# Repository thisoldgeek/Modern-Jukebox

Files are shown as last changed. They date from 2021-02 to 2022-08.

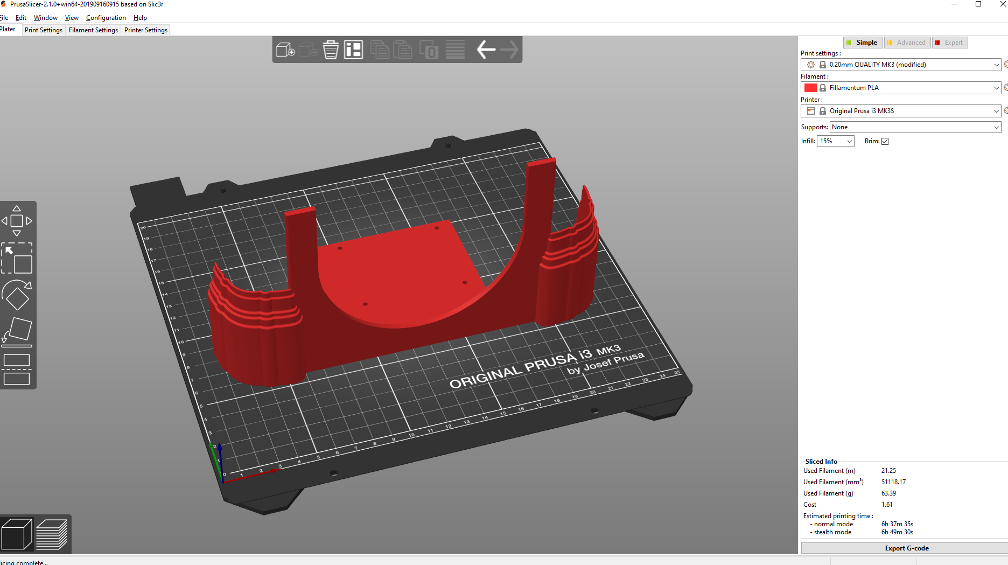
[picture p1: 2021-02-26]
3D-Prints/Bottom.png

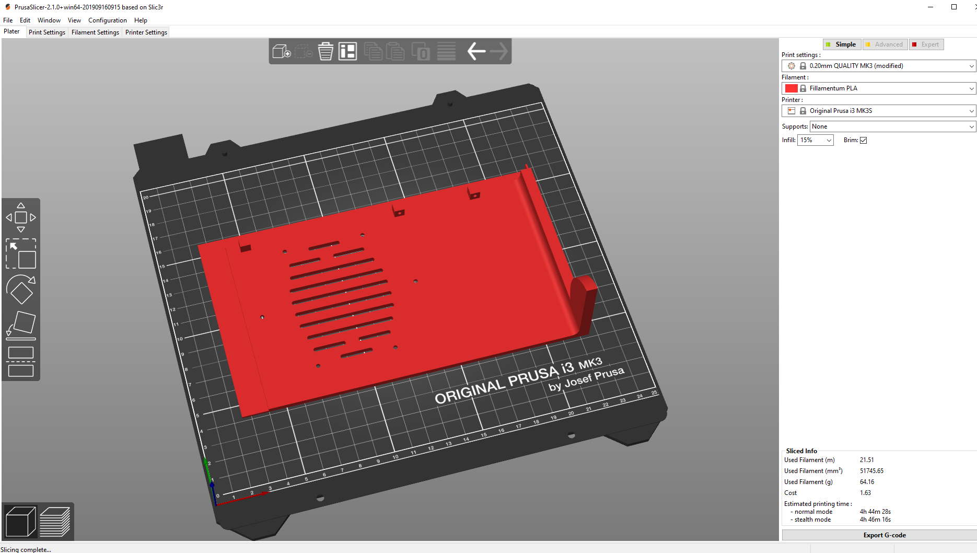
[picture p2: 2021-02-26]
3D-Prints/CaseLeft.png

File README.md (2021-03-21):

# **Modern Jukebox**
Modern-Jukebox-Small
 	 	
# *Attributions:*
Classic Jukebox by Marco Gregorio 
https://grabcad.com/library/classic-jukebox-1

Arduino sketch, Music Visualizer by Michael Bartlett
https://learn.sparkfun.com/tutorials/interactive-led-music-visualizer/all

## *Description:*
A 3D-printed Jukebox powered by Volumio, with NeoPixel LEDs that react to sound/music.
Plays your own music, web radio, Pandora, Spotify and Apple AirPlay.

See the posting at:
https://www.hackster.io/thisoldgeek/modern-jukebox-bd1f4c

## *Required Hardware:*
* raspberry pi 3/4
* UCTronics Touch Screen 5in HDMI display, https://www.amazon.com/gp/product/B07VV7RL7Y/ref=ppx_yo_dt_b_search_asin_title?ie=UTF8&psc=1&fpw=alm
* 2x Dayton Audio RS100-8 Speakers (Parts Express)
* Adafruit perma-proto HAT, https://www.adafruit.com/product/2310
* Adafruit NeoPixel string 60 per Meter, https://www.adafruit.com/product/1461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
* IQAudio Pi Digi-Amp Plus, https://www.raspberrypi.org/products/iqaudio-digiamp-plus/
* HDMI 90 degree to 270 degree adapter, https://www.amazon.com/gp/product/B00Y7UT6EK/ref=ppx_yo_dt_b_search_asin_title?ie=UTF8&psc=1&fpw=alm
* HDMI flat, short cable: https://www.amazon.com/gp/product/B07RL574BB/ref=ppx_yo_dt_b_search_asin_title?ie=UTF8&psc=1&fpw=alm
* Miscellaneous screws, nuts, standoffs, 14AWG wire, jumper wires

## *Fabrication:*
* 3D print files in STL_files folder
* 3D printed case required; back case cover 3d parts optional
* See docs folder for 3D print settings
* Hot glue gun
* CA glue
* Soldeing Iron

## *Configuration:*
* Download and install Volumio; download and install Arduino sketch (*.ino) from this repo

## *REQUIRED:*
Intentionally blank

## *More Information:*
See the build log at https://www.hackster.io/thisoldgeek/modern-jukebox-bd1f4c
## *Update 02-25-2021:*
Initial install.

#

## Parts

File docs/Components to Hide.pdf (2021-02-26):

- Juke-enfeite lateral:2
- Juke-enfeite lateral:3
- Juke-button-panel
- Juke-frente-wurlitzer
- Juke-moeda-1:1
- Juke-base neon2:1
- Juke-tocadisco:1
- Juke-prato:1
- Juke-coin-out:1
- Juke-torre-braço:1
- Juke-moeda-outro:1
- juke espelhos lat:1
- juke espelhos lat:2
- juke espelhos lat:3
- juke espelhos lat:5
- juke espelhos lat:6
- juke lamp:1
- Peça3
- juke tecido falante:1

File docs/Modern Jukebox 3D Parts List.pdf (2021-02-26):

In Component | Name | Description | Looks Like This
Juke-madeira porta-1 | Arch | Together with Bottom, forms main body of jukebox.Frames the Grille

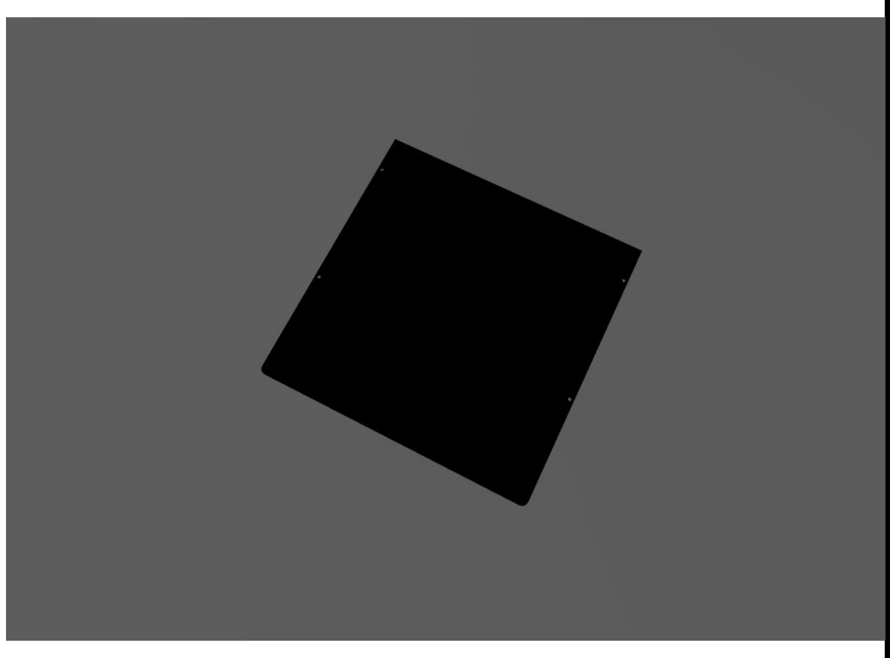
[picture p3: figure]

Juke-madeira:1 | Back Cover Bottom | Attached to Left/Right Panels to close the case

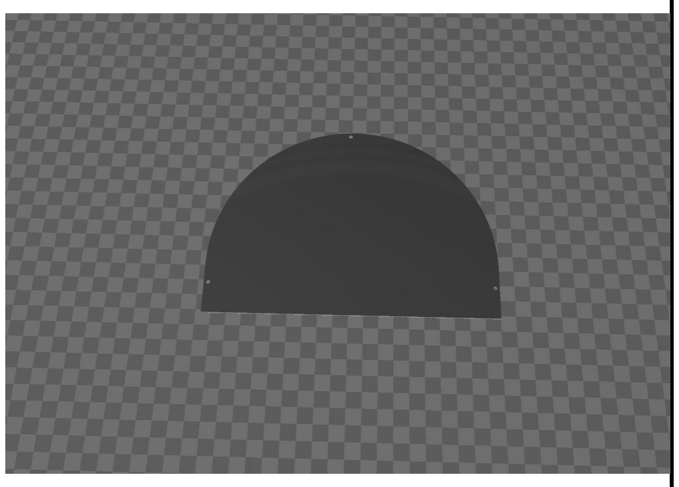
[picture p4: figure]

Juke-madeira:1 | Back Cover Top | Attached to Case Arch to close the case

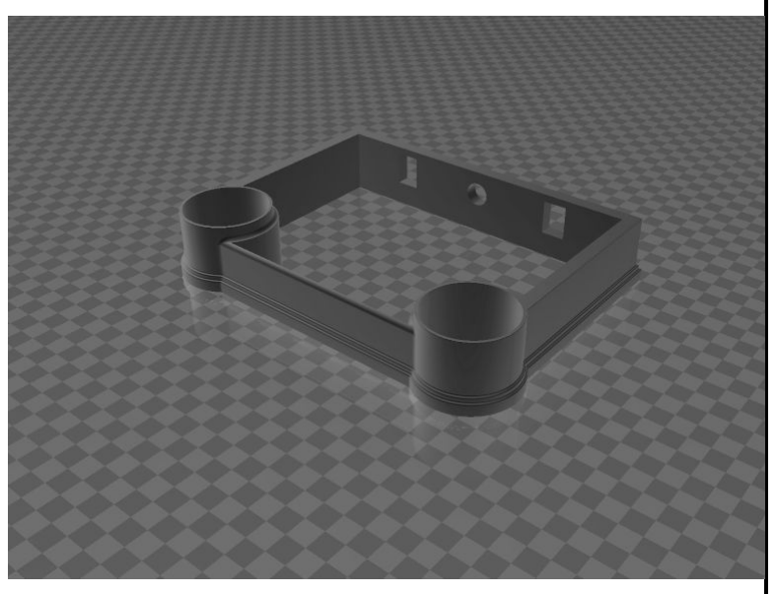
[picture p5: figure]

Jukebox - base inferior-1 | Base with switches | Attaches beneath main body of jukebox

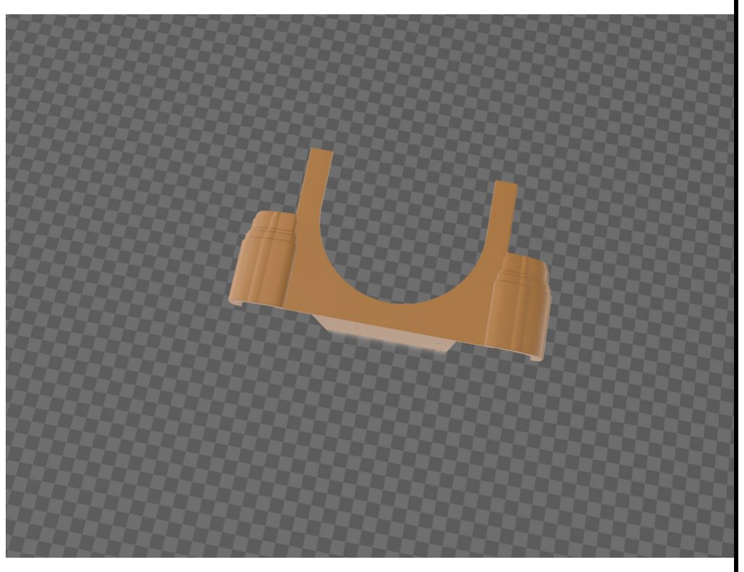
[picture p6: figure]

Juke-madeira porta-1 | Bottom | Main body of jukebox

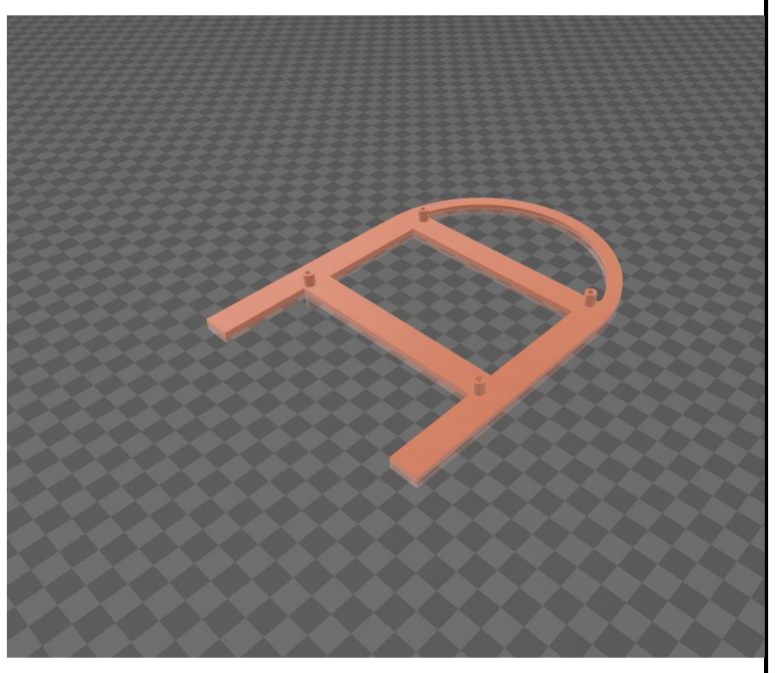
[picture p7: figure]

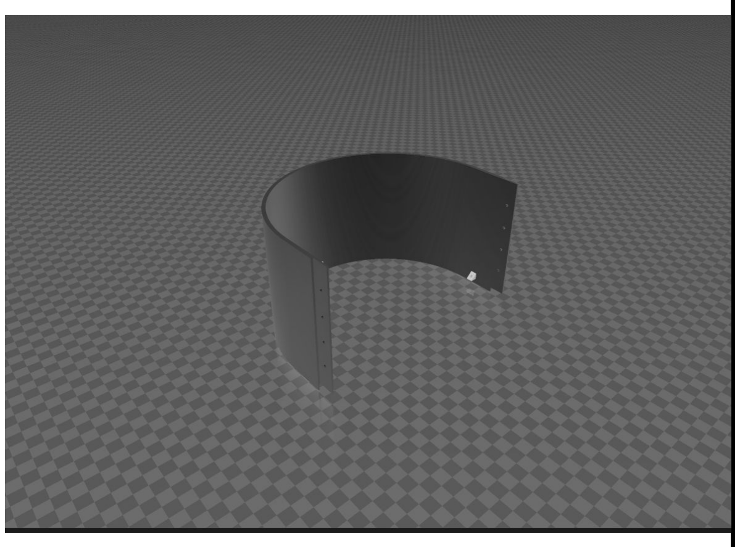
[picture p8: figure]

Juke-madeira:1 | Case Arch | Top arch behind neon tubes. Attached to left and right panels.

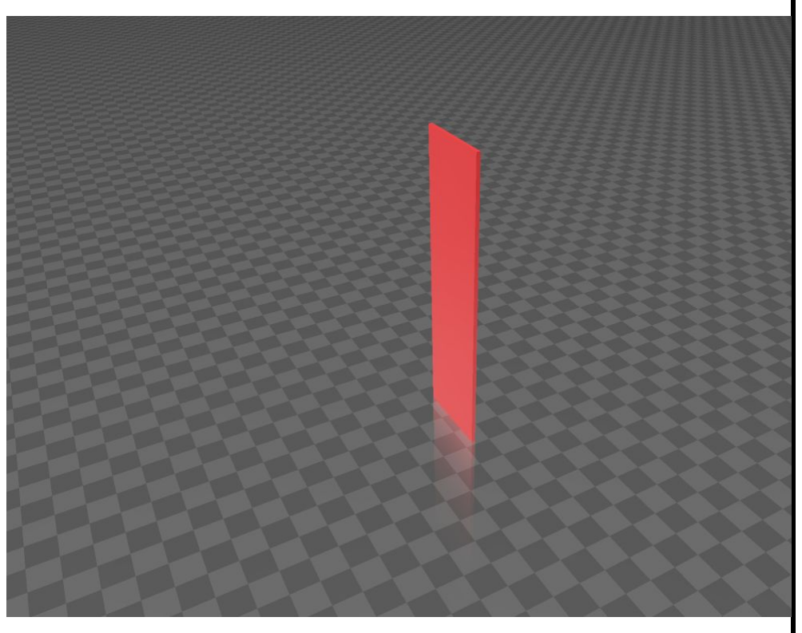
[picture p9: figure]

Juke-madeira:1 | Case Joint Cover | Hides the joint between the arch and the side panels. Two required.

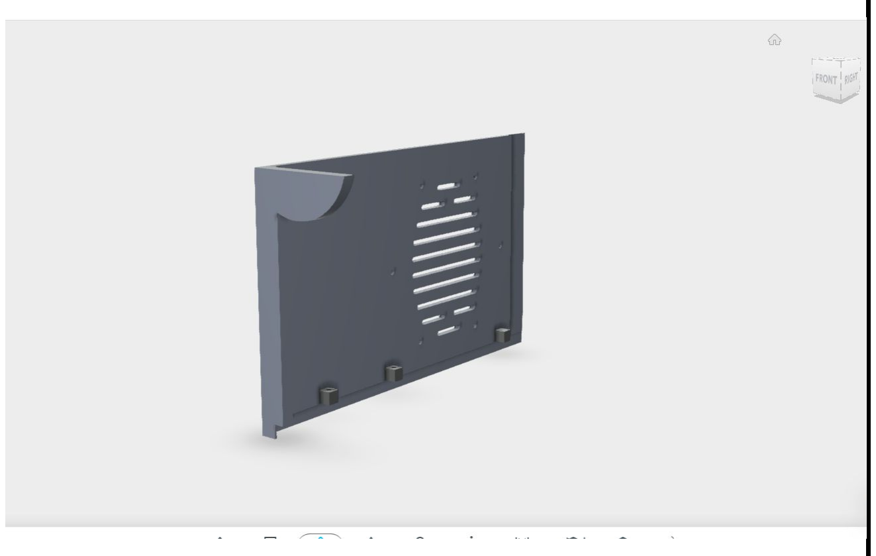
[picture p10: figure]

Juke-madeira:1 | Case Left | As you face the jukebox,case left panel behind the neon tubes.


Juke-madeira:1 | Case Right | As you face the jukebox, case right panel behind the neon tubes.


Juke-grande frontal2:1 | Grille | “Speaker” grille. Actually just a decorative piece. Speakers will be mounted on case sides.


Juke-grande frontal2:1 | Grille LED Holder | Holds an LED behind the grille light and acts as a light blocker on the back of the light


Juke-grande frontal2:1 | Grille Light | Illuminated insert for grille


Juke-neon interno:1 | Grille Tube | “Neon” frame around grille. Short string of LEDs will attach here.
Juke-neon-1 | Neon 1 Arch | Top arch to connect two side “neon” tubes. Thread long LED strip through this assembled component.


Juke-neon-1 | Neon 2 Tubes | Connects to Neon Arch. Thread long LED strip through these assembled components. Two tubes required.


JJuke-enfeite lateral-superior3 | Neon Tube Fan Decoration | Attached on top of Neon Tube Red Cover. Two required.


Juke-enfeite lateral:1 | Neon Tube Ornament | Attached on bottom of Neon Tube Red Cover. Two required.


Juke-neon:1 | Neon Tube Red Cover | Covers joints where neon tubes meet neon arch. Two required.


Juke-madeira:1 | Speaker Mount Ring | Adapter so Dayton Audio rs100-8 speakers will mount flush to panels. Two required.


Juke-topo-enfeite:1 | Top Ornament | Attached at top, center of Neon Arch. Two required (two bodies in STL file)..


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
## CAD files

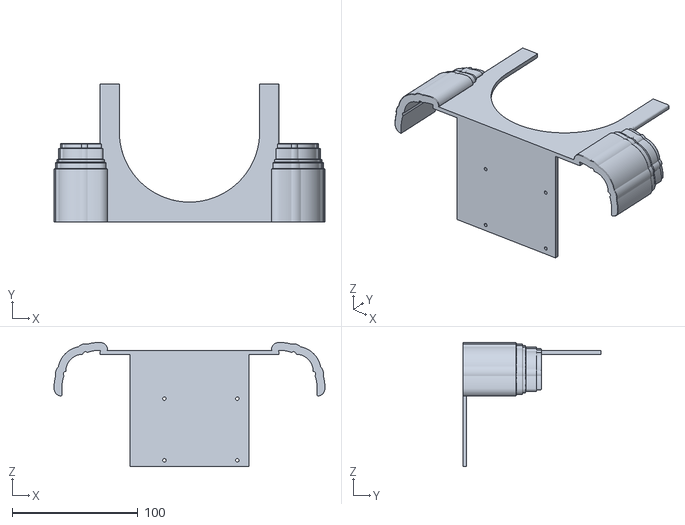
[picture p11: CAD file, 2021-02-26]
STL-files/Bottom.stl
215.5 x 110.0 x 98.8

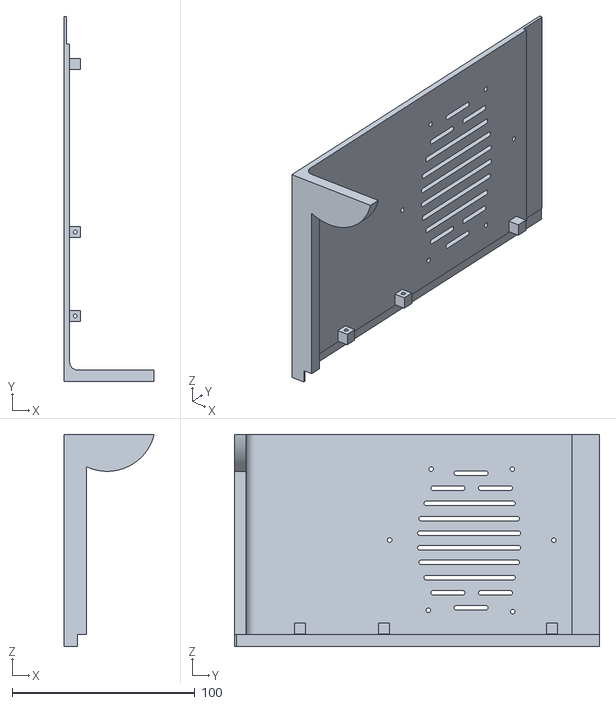
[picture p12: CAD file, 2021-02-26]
STL-files/CaseLeft.stl
49.6 x 200.0 x 116.2

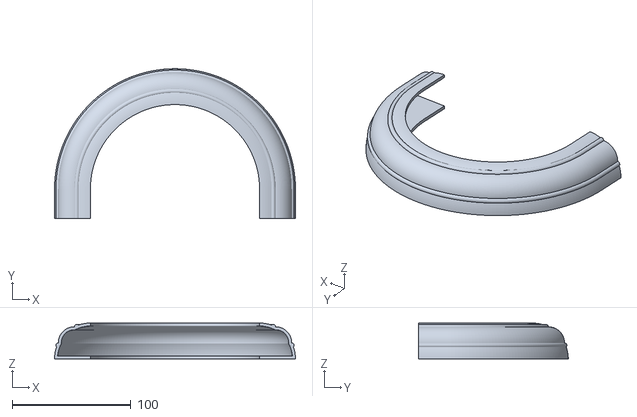
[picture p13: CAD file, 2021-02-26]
STL-files/Neon1Arch.stl
203.0 x 126.0 x 30.2

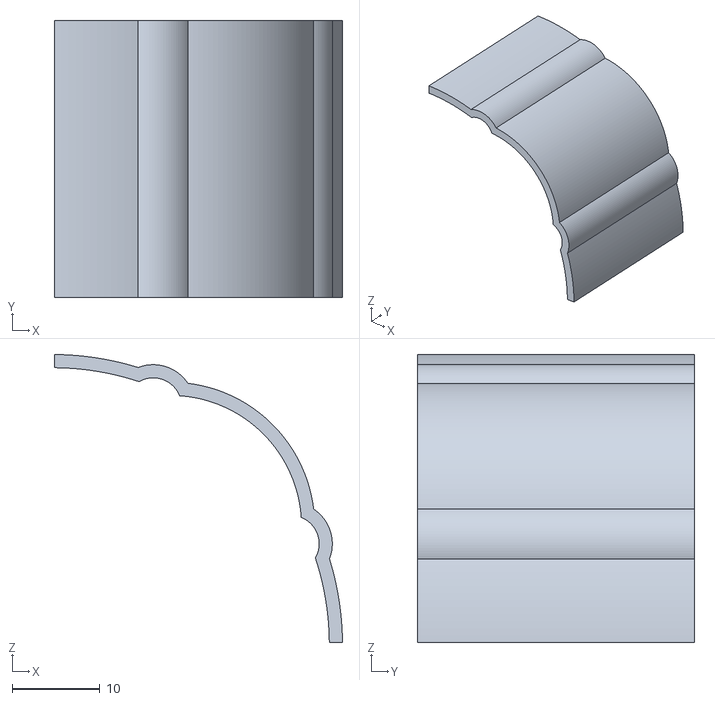
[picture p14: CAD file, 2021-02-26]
STL-files/NeonTubeRedCover.stl
32.7 x 31.5 x 32.7

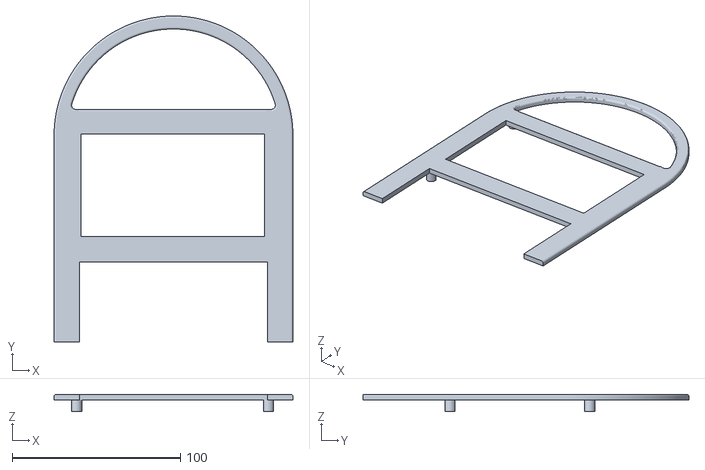
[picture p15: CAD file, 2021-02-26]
STL-files/Arch.stl
142.0 x 193.7 x 10.2

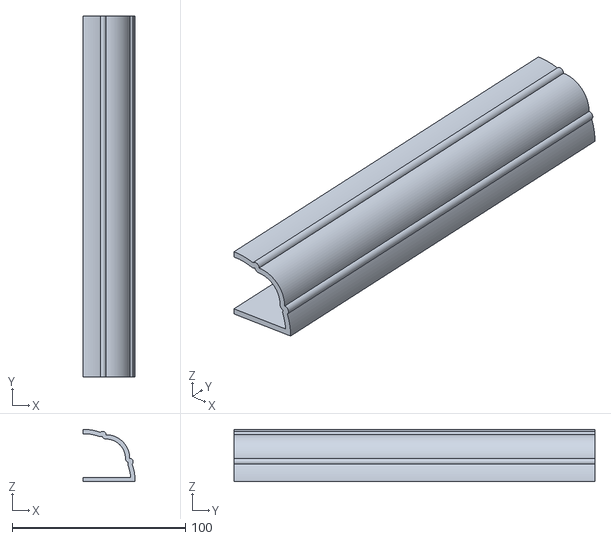
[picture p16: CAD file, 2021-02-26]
STL-files/Neon2Tubes.stl
30.2 x 208.2 x 30.2

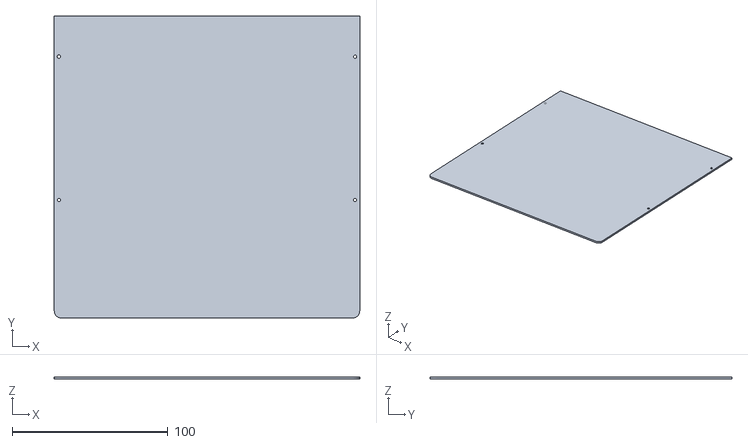
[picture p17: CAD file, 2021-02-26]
STL-files/BackCoverBottom.stl
196.0 x 193.7 x 1.50

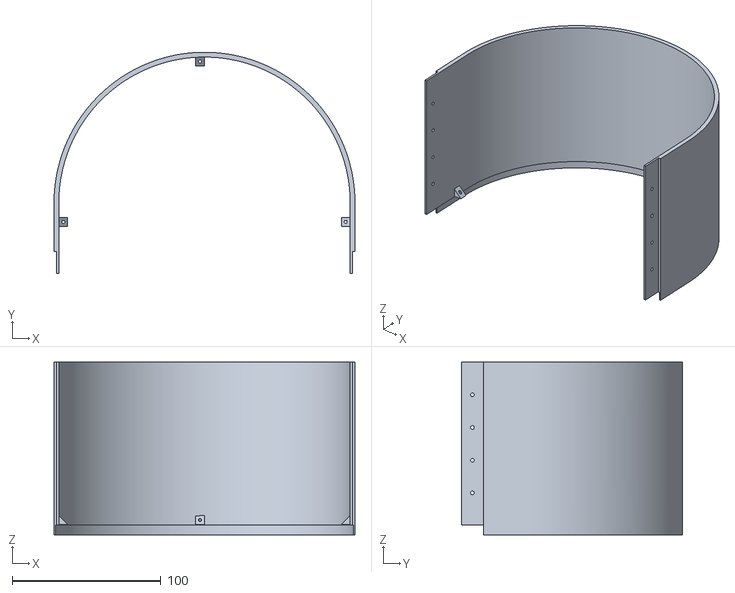
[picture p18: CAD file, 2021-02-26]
STL-files/CaseArch.stl
202.5 x 149.0 x 116.2

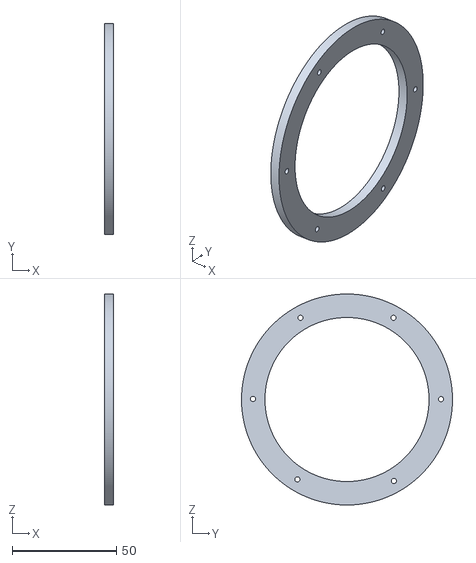
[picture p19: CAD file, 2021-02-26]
STL-files/SpeakerMountRing.stl
4.50 x 101.0 x 101.0

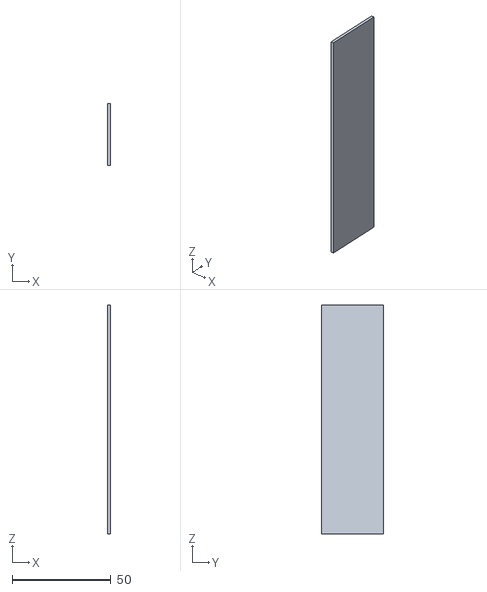
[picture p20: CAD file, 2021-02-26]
STL-files/CaseJointCover.stl
1.50 x 31.5 x 116.2

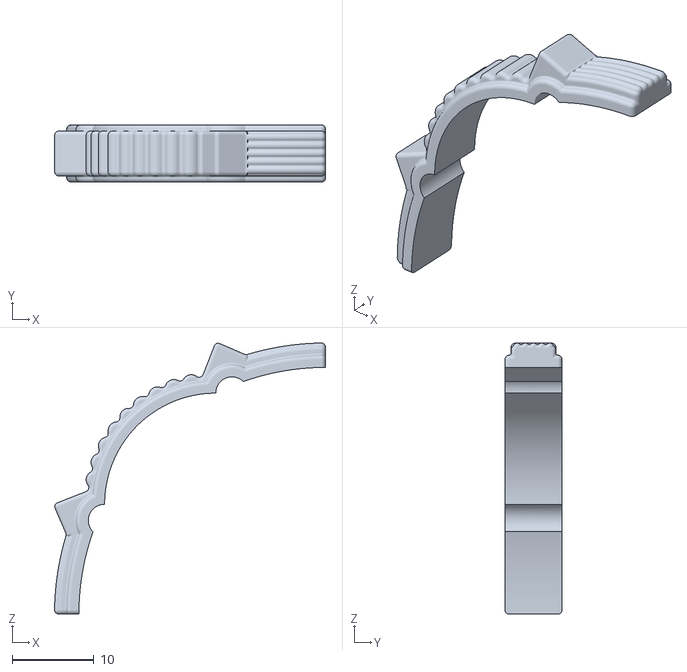
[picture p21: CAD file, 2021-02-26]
STL-files/NeonTubeOrnament.stl
33.2 x 7.00 x 33.2

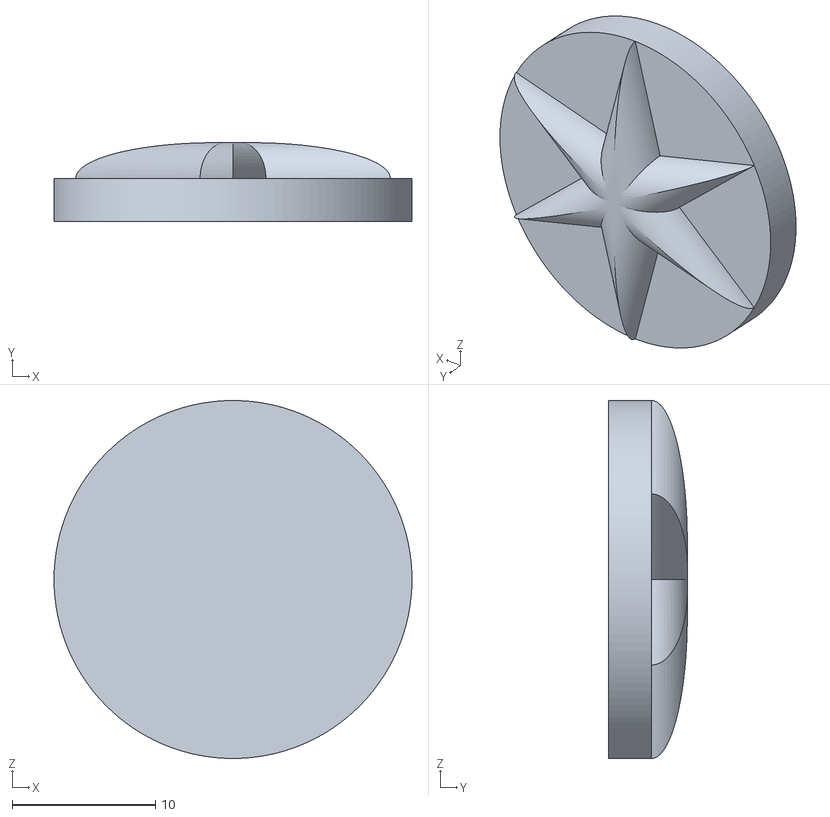
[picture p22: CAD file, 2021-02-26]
STL-files/GrilleLight.stl
25.0 x 5.50 x 25.0

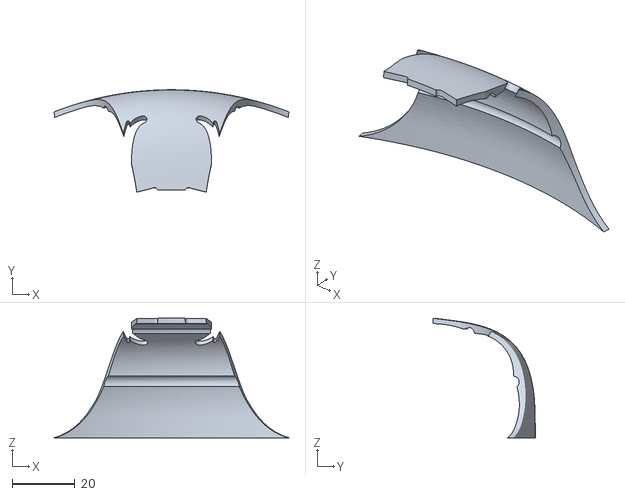
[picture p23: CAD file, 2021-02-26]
STL-files/TopRedOrnament.stl
75.2 x 32.8 x 38.2

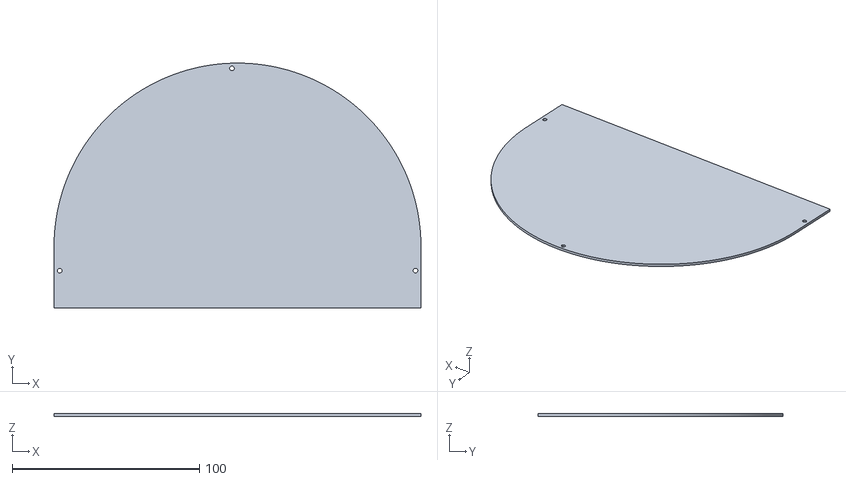
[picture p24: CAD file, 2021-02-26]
STL-files/BackCoverTop.stl
196.0 x 130.7 x 1.50

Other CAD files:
STL-files/CaseRight.stl
STL-files/GrilleTube.stl
STL-files/BaseWithSwitches.stl
STL-files/GrilleLEDHolder.stl

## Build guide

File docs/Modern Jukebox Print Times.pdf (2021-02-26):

Print Object | Print Time Supports Required?
Arch | 2:08:00
Back Cover Bottom | 4:04:00
Back Cover Top | 2:15:00
Base with Switches | 8:42:00
Bottom | 6:37:00
Case Arch | 12:08:00
Case Joint Cover | 0:28:00
Case Left | 4:44:00
Case Right | 4:45:00
Grille | 2:48:00
Grille LED Holder | 0:35:00
Grille Light | 0:12:00
Grille Tube | 4:25:00
Neon Arch | 8:48:00
Neon Tubes | 5:35:00
Neon Tube Fan Decoration | 0:26:00
Neon Tube Ornament | 0:19:00
Neon Tube Red Cover | 0:58:00
Speaker Mount Ring | 0:57:00
Top Ornament | 2:29:00
Top Red Ornament | 1:54:00
Total Print Time | 75:17:00

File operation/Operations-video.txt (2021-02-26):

Operations - https://youtu.be/HVOtVooQ_8A

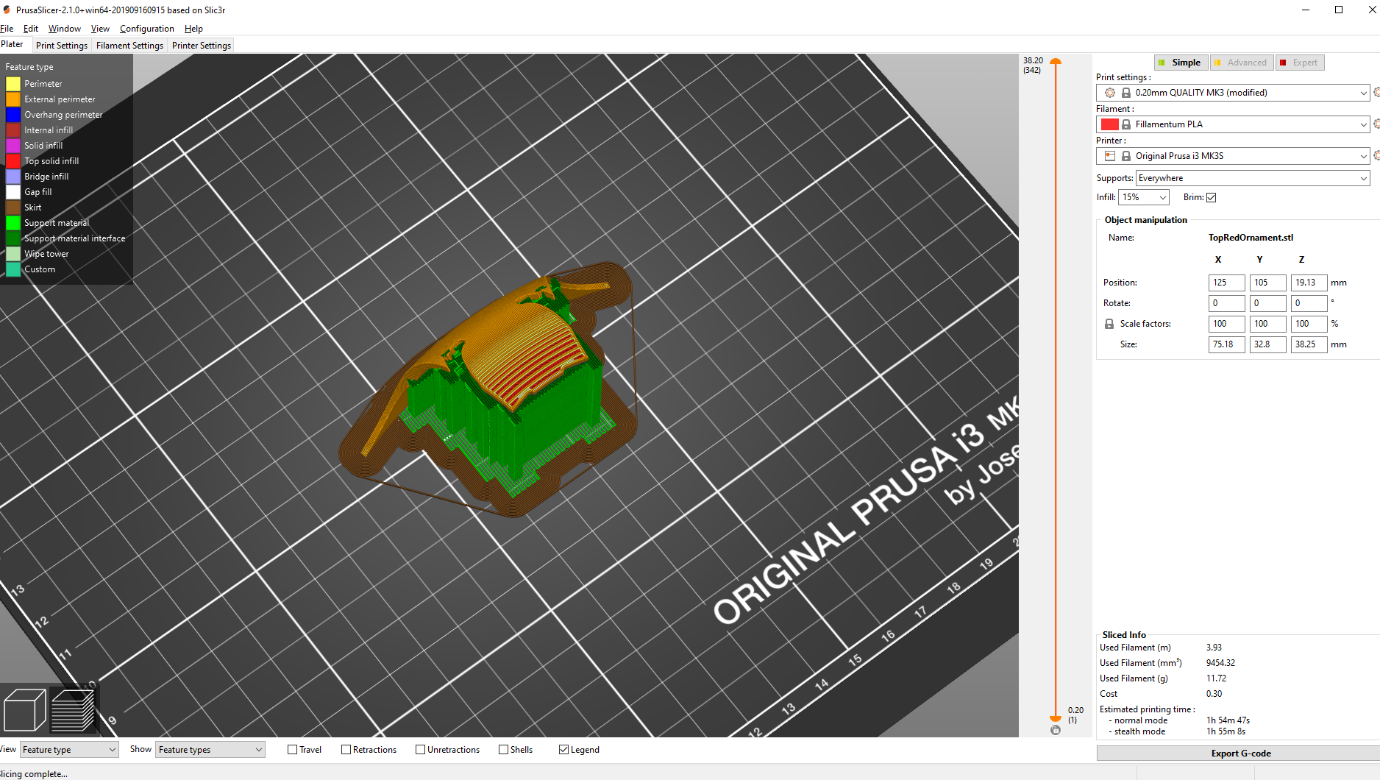
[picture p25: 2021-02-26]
3D-Prints/TopRedOrnament.png

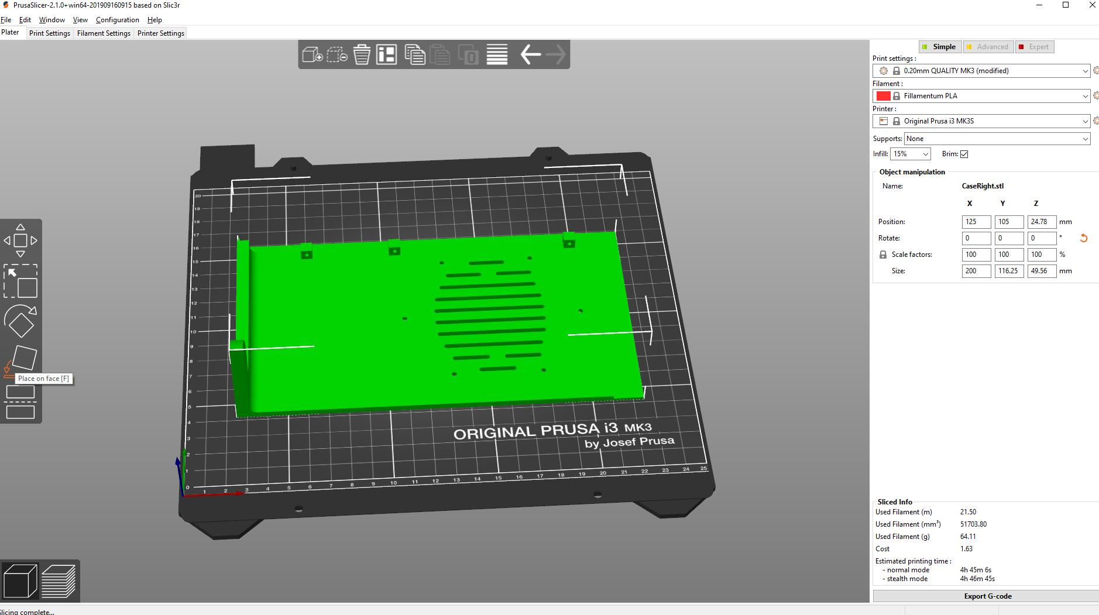
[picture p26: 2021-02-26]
3D-Prints/CaseRight.png

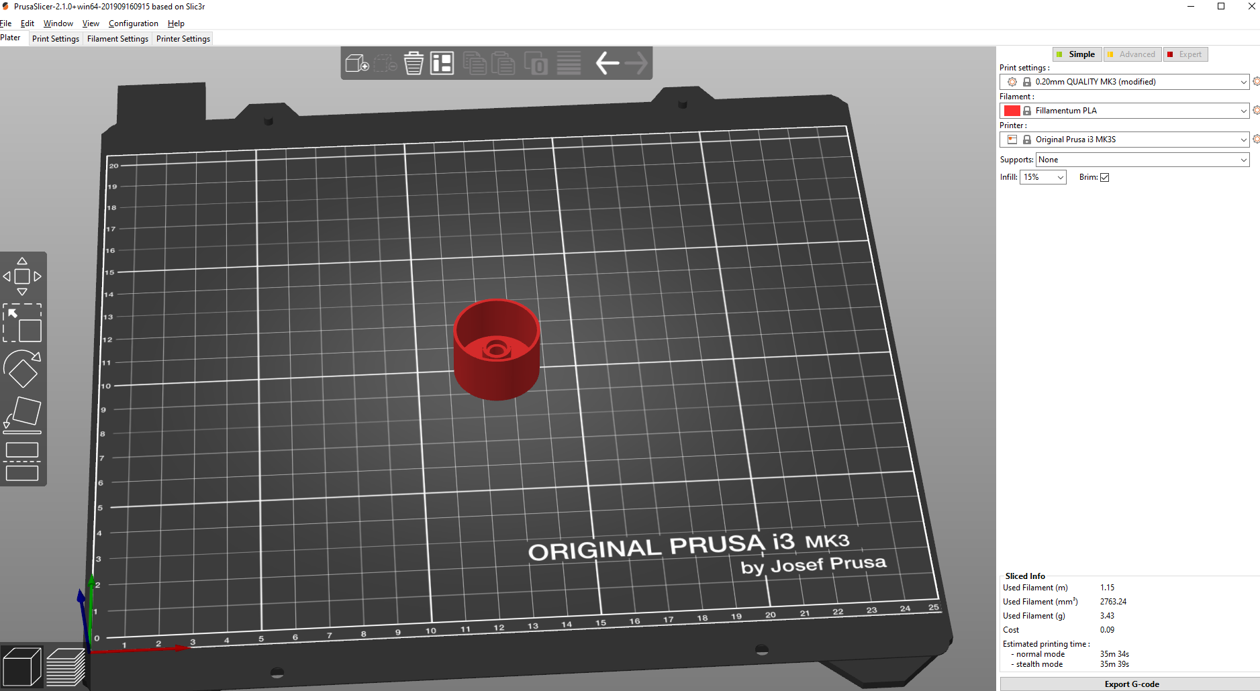
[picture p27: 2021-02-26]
3D-Prints/GrilleLEDHolder.png

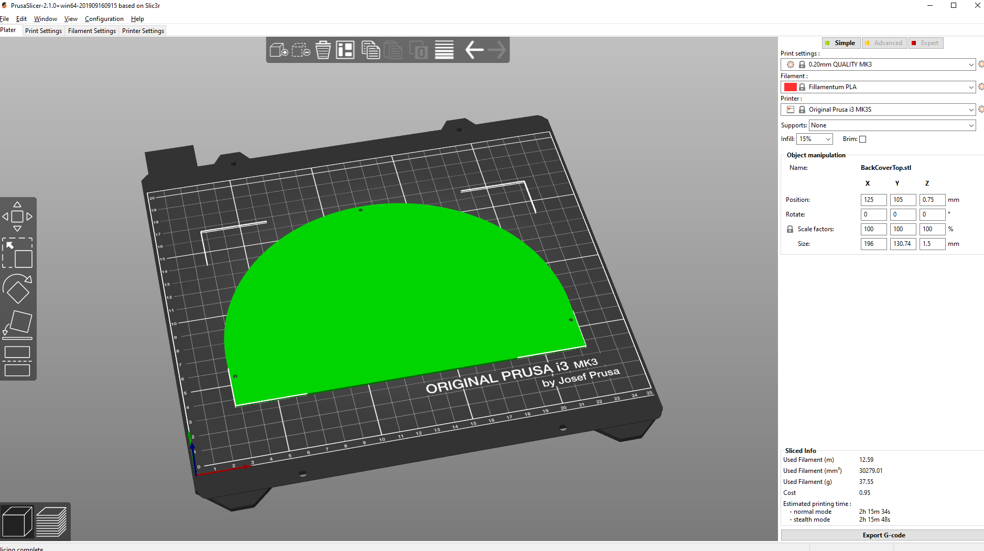
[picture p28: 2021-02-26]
3D-Prints/BackCoverTop.png

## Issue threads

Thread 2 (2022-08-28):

In animated lights mode, the lights don't track evenly up each side

Mark-Kiwi, 2022-08-28:
When switched to animated lights mode, I noticed the lights are not level as they sequence up each side.

To fix this, change the code as follows:
line 343
strand.setPixelColor(strand.numPixels()-(i+q), Wheel( (i+j) % 255));    //turn every third pixel on
change to
strand.setPixelColor(strand.numPixels()-1)-(i+q), Wheel( (i+j) % 255));    //turn every third pixel on

and line 351
strand.setPixelColor(strand.numPixels()-(i+q), 0);        //turn every third pixel off
change to
strand.setPixelColor((strand.numPixels()-1)-(i+q), 0);        //turn every third pixel off

thisoldgeek, 2022-08-29:
Applied

Closed 2022-08-29.

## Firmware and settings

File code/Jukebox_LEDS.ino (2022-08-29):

/* SparkFun Addressable RGB LED Sound and Music Visualizer Tutorial Arduino Code
 * by: Michael Bartlett
 * SparkFun Electronics
 * date: 2/7/16
 * license: Creative Commons Attribution-ShareAlike 4.0 (CC BY-SA 4.0)
 * Do whatever you'd like with this code, use it for any purpose.
 * Please attribute and keep this license.
*/
// Last Updated 20201211 15:30
//Libraries
#include <Adafruit_NeoPixel.h>  //Library to simplify interacting with the LED strand
#ifdef __AVR__
#include <avr/power.h>   //Includes the library for power reduction registers if your chip supports them. 
#endif                   //More info: http://www.nongnu.org/avr-libc/user-manual/group__avr__power.htlm

//Constants (change these as necessary)
#define LED_PIN   7  //Pin for the pixel tube strand. Can be analog or digital.
#define grille_LED_PIN   13  //Pin for the pixel grille strand. Can be analog or digital.
#define LED_TOTAL 36 //Change this to the number of LEDs in your strand
#define grille_LED_TOTAL 22 //Change this to the number of LEDs in your grille strand.
#define LED_HALF  LED_TOTAL/2
#define grille_LED_HALF  grille_LED_TOTAL/2
#define VISUALS   6   //Change this accordingly if you add/remove a visual in the switch-case in Visualize()

#define AUDIO_PIN A5  //Pin for the envelope of the sound detector
//#define KNOB_PIN  A1  //Pin for the trimpot 10K
#define BUTTON_1  6   //Button 1 cycles color palettes
#define BUTTON_2  5   //Button 2 cycles visualization modes
#define BUTTON_3  4   //Button 3 sw_poss shuffle mode (automated changing of color and visual)

//////////<Globals>
//  These values either need to be remembered from the last pass of loop() or
//  need to be accessed by several functions in one pass, so they need to be global.

// strand = outer "neon" tubes, used for music visualization
// strand2 = inner "grille_LED" tubes, constanly changing patterns. Not in sync with music
Adafruit_NeoPixel strand = Adafruit_NeoPixel(LED_TOTAL, LED_PIN, NEO_GRB + NEO_KHZ800);  //LED strand objects
Adafruit_NeoPixel grille_LED_strand = Adafruit_NeoPixel(grille_LED_TOTAL, grille_LED_PIN, NEO_GRB + NEO_KHZ800);  //LED grille strand objects


uint16_t gradient = 0; //Used to iterate and loop through each color palette gradually

//IMPORTANT:
//  This array holds the "threshold" of each color function (i.e. the largest number they take before repeating).
//  The values are in the same order as in ColorPalette()'s switch case (Rainbow() is first, etc). This is simply to
//  keep "gradient" from overflowing, the color functions themselves can take any positive value. For example, the
//  largest value Rainbow() takes before looping is 1529, so "gradient" should reset after 1529, as listed.
//     Make sure you add/remove values accordingly if you add/remove a color function in the switch-case in ColorPalette().
uint16_t thresholds[] = {1529, 1019, 764, 764, 764, 1274};

uint8_t palette = 0;  //Holds the current color palette.
uint8_t visual = 0;   //Holds the current visual being displayed.
uint8_t volume = 0;   //Holds the volume level read from the sound detector.
uint8_t last = 0;     //Holds the value of volume from the previous loop() pass.

float maxVol = 15;    //Holds the largest volume recorded thus far to proportionally adjust the visual's responsiveness.
//float knob = 1023.0;  //Holds the percentage of how twisted the trimpot is. Used for adjusting the max brightness.
float avgBump = 0;    //Holds the "average" volume-change to trigger a "bump."
float avgVol = 0;     //Holds the "average" volume-level to proportionally adjust the visual experience.
float shuffleTime = 0;  //Holds how many seconds of runtime ago the last shuffle was (if shuffle mode is on).

////////////////////////////////////////////////////////////////////////////////////////////////////////////////
//NOTE: The reason "average" is quoted is because it is not a true mathematical average. This is because I have
//      found what I call a "sequenced average" is more successful in execution than a real average. The difference
//      is that the sequenced average doesn't use the pool of all values recorded thus far, but rather averages the
//      last average and the current value received (in sequence). Concretely:
//
//          True average: (1 + 2 + 3) / 3 = 2
//          Sequenced: (1 + 2) / 2 = 1.5 --> (1.5 + 3) / 2 = 2.25  (if 1, 2, 3 was the order the values were received)
//
//      All "averages" in the program operate this way. The difference is subtle, but the reason is that sequenced
//      averages are more adaptive to changes in the overall volume. In other words, if you went from loud to quiet,
//      the sequenced average is more likely to show an accurate and proportional adjustment more fluently.
////////////////////////////////////////////////////////////////////////////////////////////////////////////////

//bool shuffle = false;  //sw_poss shuffle mode.
bool shuffle = true;  //sw_poss shuffle mode.
bool bump = false;     //Used to pass if there was a "bump" in volume

//For Traffic() visual
int8_t pos[LED_TOTAL] = { -2};    //Stores a population of color "dots" to iterate across the LED strand.
uint8_t rgb[LED_TOTAL][3] = {0};  //Stores each dot's specific RGB values.

//For Snake() visual
bool left = false;  //Determines the direction of iteration. Recycled in PaletteDance()
int8_t dotPos = 0;  //Holds which LED in the strand the dot is positioned at. Recycled in most other visuals.
float timeBump = 0; //Holds the time (in runtime seconds) the last "bump" occurred.
float avgTime = 0;  //Holds the "average" amount of time between each "bump" (used for pacing the dot's movement).

//////////</Globals>


//////////<Standard Functions>

// Selection Switch Pin Number
int sw_pos1 = 2;   //uses lights to music Visualizer routines
int sw_pos2 = 4;   //uses animated lights that don't react to music
int switch_choice; //whether switch is in 1, 2, or Off (== 0, center position)


void setup() {    //Like it's named, this gets ran before any other function.
  // Note: Following code works directly on Arduino Uno, 
  //       but on Micro, different behavior




  //Serial.begin(9600); //Sets data rate for serial data transmission.
  //Serial.println("Program Starting...");

  //Defines the buttons pins to be input.
  pinMode(BUTTON_1, INPUT); pinMode(BUTTON_2, INPUT); pinMode(BUTTON_3, INPUT);

  //Write a "HIGH" value to the button pins.
  digitalWrite(BUTTON_1, HIGH); digitalWrite(BUTTON_2, HIGH); digitalWrite(BUTTON_3, HIGH);

  strand.begin(); //Initialize the LED strand object.
  strand.show();  //Show a blank strand, just to get the LED's ready for use.

  grille_LED_strand.begin(); //Initialize the LED grille_LED_stran object.
  grille_LED_strand.show();  //Show a blank stran around grille_LED, just to get the LED's ready for use.

  pinMode(sw_pos1, INPUT_PULLUP);
  pinMode(sw_pos2, INPUT_PULLUP);

  // Startup Routine for Grille Lights
  // Some example procedures showing how to display to the pixels:
  
  //StrandtheaterChaseRainbow(50);
  /*
  colorWipe(grille_LED_strand.Color(255, 0, 0), 50); // Red
  colorWipe(grille_LED_strand.Color(0, 255, 0), 50); // Green
  colorWipe(grille_LED_strand.Color(0, 0, 255), 50); // Blue
  //colorWipe(grille_LED_strand.Color(0, 0, 0, 255), 50); // White RGBW
  // Send a theater pixel chase in...
  
  theaterChase(grille_LED_strand.Color(127, 127, 127), 50); // White
  theaterChase(grille_LED_strand.Color(127, 0, 0), 50); // Red
  theaterChase(grille_LED_strand.Color(0, 0, 127), 50); // Blue
  */ 
  
  // The following functions will run and leave the grille LEDs on 
  //rainbow(20);
  rainbowCycle(20);
  
}

void loop()
{
 check_sw_position();
  
 if (switch_choice == 1)
 {  
    lights_to_music();
  }
 if (switch_choice == 2)
  {
    lights_to_patterns();
  }

// NO outside tube LEDs on 
 if (switch_choice == 3)
   {
   for(int i=0; i< strand.numPixels(); i++) 
   {
      strand.setPixelColor(i, 0,0,0);
    }
    strand.show();
   } 
}


void check_sw_position()
{
 // Internal pullup on sw_pos1 and sw_pos2 means their default value is HIGH
  // sw_pos1 HIGH = switch position 1 selected
  // sw_pos2 HIGH = switch position 2 selected
  // sw_pos1 HIGH and sw_pos2 HIGH = switch position OFF/CENTER
  
  if (digitalRead(sw_pos1) == HIGH && digitalRead(sw_pos2) == LOW)
  //if sw_pos2 == LOW, use Visualizer routines
  {
    switch_choice = 1;
  }

  else if (digitalRead(sw_pos2) == HIGH && digitalRead(sw_pos1) == LOW)
  //else if sw_pos1 == LOW, use animation routines that don't react to music
  {
    switch_choice = 2;
  }
  
  else 
  {
   switch_choice = 3;
   for(int i=0; i< strand.numPixels(); i++) {
      strand.setPixelColor(i, 0,0,0);
    }
    strand.show();
  }
}
void lights_to_music() {  //This is where the magic happens. This loop produces each frame of the visual.

  volume = analogRead(AUDIO_PIN);       //Record the volume level from the sound detector
  //knob = analogRead(KNOB_PIN) / 1023.0; //Record how far the trimpot is twisted

  //Sets a threshold for volume.
  //  In practice I've found noise can get up to 15, so if it's lower, the visual thinks it's silent.
  //  Also if the volume is less than average volume / 2 (essentially an average with 0), it's considered silent.
  if (volume < avgVol / 2.0 || volume < 15) volume = 0;

  else avgVol = (avgVol + volume) / 2.0; //If non-zeo, take an "average" of volumes.

  //If the current volume is larger than the loudest value recorded, overwrite
  if (volume > maxVol) maxVol = volume;

  //Check the Cycle* functions for specific instructions if you didn't include buttons in your design.
  ////////////////////////////////////////////////////////////////////////////////////////////////////
  CyclePalette();  //Changes palette for shuffle mode or button press.

  CycleVisual();   //Changes visualization for shuffle mode or button press.

  //sw_posShuffle(); //sw_poss shuffle mode. Delete this if you didn't use buttons.
  ////////////////////////////////////////////////////////////////////////////////////////////////////

  //This is where "gradient" is modulated to prevent overflow.
  if (gradient > thresholds[palette]) {
    gradient %= thresholds[palette] + 1;

    //Everytime a palette gets completed is a good time to readjust "maxVol," just in case
    //  the song gets quieter; we also don't want to lose brightness intensity permanently
    //  because of one stray loud sound.
    maxVol = (maxVol + volume) / 2.0;
  }

  //If there is a decent change in volume since the last pass, average it into "avgBump"
  if (volume - last > 10) avgBump = (avgBump + (volume - last)) / 2.0;

  //If there is a notable change in volume, trigger a "bump"
  //  avgbump is lowered just a little for comparing to make the visual slightly more sensitive to a beat.
  bump = (volume - last > avgBump * .9);  

  //If a "bump" is triggered, average the time between bumps
  if (bump) {
    avgTime = (((millis() / 1000.0) - timeBump) + avgTime) / 2.0;
    timeBump = millis() / 1000.0;
  }

  Visualize();   //Calls the appropriate visualization to be displayed with the globals as they are.

  gradient++;    //Increments gradient

  last = volume; //Records current volume for next pass

  delay(30);     //Paces visuals so they aren't too fast to be enjoyable
}
//////////</Standard Functions>

// Fill the dots one after the other with a color
void colorWipe(uint32_t c, uint8_t wait) {
  for(uint16_t i=0; i<grille_LED_strand.numPixels(); i++) {
    grille_LED_strand.setPixelColor(i, c);
    grille_LED_strand.show();
    delay(wait);
  }
}

void rainbow(uint8_t wait) {
  uint16_t i, j;

  for(j=0; j<256; j++) {
    for(i=0; i<grille_LED_strand.numPixels(); i++) {
      grille_LED_strand.setPixelColor(i, Wheel((i+j) & 255));
    }
    grille_LED_strand.show();
    delay(wait);
  }
}

// Slightly different, this makes the rainbow equally distributed throughout
void rainbowCycle(uint8_t wait) {
  uint16_t i, j;

  for(j=0; j<256*5; j++) { // 5 cycles of all colors on wheel
    for(i=0; i< grille_LED_strand.numPixels(); i++) {
      grille_LED_strand.setPixelColor(i, Wheel(((i * 256 / grille_LED_strand.numPixels()) + j) & 255));
    }
    grille_LED_strand.show();
    delay(wait);
  }
}

//Theatre-style crawling lights.
void theaterChase(uint32_t c, uint8_t wait) {
  for (int j=0; j<10; j++) {  //do 10 cycles of chasing
    for (int q=0; q < 3; q++) {
      for (uint16_t i=0; i < grille_LED_strand.numPixels(); i=i+3) {
        grille_LED_strand.setPixelColor(i+q, c);    //turn every third pixel on
      }
      grille_LED_strand.show();

      delay(wait);

      for (uint16_t i=0; i < grille_LED_strand.numPixels(); i=i+3) {
        grille_LED_strand.setPixelColor(i+q, 0);        //turn every third pixel off
      }
    }
  }
}

//Theatre-style crawling lights with rainbow effect
void grilleChaseRainbow(uint8_t wait) {
  for (int j=0; j < 256; j++) {     // cycle all 256 colors in the wheel
    for (int q=0; q < 3; q++) {
      for (uint16_t i=0; i < grille_LED_strand.numPixels(); i=i+3) {
        grille_LED_strand.setPixelColor(i+q, Wheel( (i+j) % 255));    //turn every third pixel on
      }
      grille_LED_strand.show();

      delay(wait);

      for (uint16_t i=0; i < grille_LED_strand.numPixels(); i=i+3) {
        grille_LED_strand.setPixelColor(i+q, 0);        //turn every third pixel off
      }
    }
  }
}

void lights_to_patterns() {
  StrandtheaterChaseRainbow(175);
}

//Theatre-style crawling lights with rainbow effect
void StrandtheaterChaseRainbow(uint8_t wait) 
{ 
  int prev_switch = switch_choice;
  // This function splits the outer LED tubes in half
  // so the chase effect crawls up each side and meets
  // in the middle of the arch, at the top
  for (int j=0; j < 256; j++) {     // cycle all 256 colors in the wheel
    for (int q=0; q < 3; q++) {
      for (uint16_t i=0; i < strand.numPixels()/2; i=i+3) {
        strand.setPixelColor(i+q, Wheel( (i+j) % 255));    //turn every third pixel on
        strand.setPixelColor(strand.numPixels()-1)-(i+q), Wheel( (i+j) % 255));     //turn every third pixel on
      }
      strand.show();

      delay(wait);

      for (uint16_t i=0; i < strand.numPixels()/2; i=i+3) {
        strand.setPixelColor(i+q, 0);        //turn every third pixel off
        strand.setPixelColor((strand.numPixels()-1)-(i+q), 0);      //turn every third pixel off
      }
    }
    check_sw_position();
    if (prev_switch != switch_choice)
      {break;}  // get out of the loop quickly
  }
}

// Input a value 0 to 255 to get a color value.
// The colours are a transition r - g - b - back to r.
uint32_t Wheel(byte WheelPos) {
  WheelPos = 255 - WheelPos;
  if(WheelPos < 85) {
    return grille_LED_strand.Color(255 - WheelPos * 3, 0, WheelPos * 3);
  }
  if(WheelPos < 170) {
    WheelPos -= 85;
    return grille_LED_strand.Color(0, WheelPos * 3, 255 - WheelPos * 3);
  }
  WheelPos -= 170;
  return grille_LED_strand.Color(WheelPos * 3, 255 - WheelPos * 3, 0);
}
//////////<Visual Functions>

//This function calls the appropriate visualization based on the value of "visual"
void Visualize() {
  switch (visual) {
    case 0: return Pulse();
    case 1: return PalettePulse();
    case 2: return Traffic();
    case 3: return Snake();
    case 4: return PaletteDance();
    case 5: return Glitter();
    case 6: return Paintball();
    default: return Pulse();
  }
}

//////////////////////////////////////////////////////////////////////////////////////////////////////////
//NOTE: The strand displays RGB values as a 32 bit unsigned integer (uint32_t), which is why ColorPalette()
//      and all associated color functions' return types are uint32_t. This value is a composite of 3
//      unsigned 8bit integer (uint8_t) values (0-255 for each of red, blue, and green). You'll notice the
//      function split() (listed below) is used to dissect these 8bit values from the 32-bit color value.
//////////////////////////////////////////////////////////////////////////////////////////////////////////


//This function calls the appropriate color palette based on "palette"
//  If a negative value is passed, returns the appropriate palette withe "gradient" passed.
//  Otherwise returns the color palette with the passed value (useful for fitting a whole palette on the strand).
uint32_t ColorPalette(float num) {
  switch (palette) {
    case 0: return (num < 0) ? Rainbow(gradient) : Rainbow(num);
    case 1: return (num < 0) ? Sunset(gradient) : Sunset(num);
    case 2: return (num < 0) ? Ocean(gradient) : Ocean(num);
    case 3: return (num < 0) ? PinaColada(gradient) : PinaColada(num);
    case 4: return (num < 0) ? Sulfur(gradient) : Sulfur(num);
    case 5: return (num < 0) ? NoGreen(gradient) : NoGreen(num);
    default: return Rainbow(gradient);
  }
}

///////////////////////////////////////////////////////////////////////////////////////////////////////////////
//NOTE: All of these visualizations feature some aspect that affects brightness based on the volume relative to
//      maxVol, so that louder = brighter. Initially, I did simple proportions (volume/maxvol), but I found this
//      to be visually indistinct. I then tried an exponential method (raising the value to the power of
//      volume/maxvol). While this was more visually satisfying, I've opted for a balance between the two. You'll
//      notice something like pow(volume/maxVol, 2.0) in the functions below. This simply squares the ratio of
//      volume to maxVol to get a more exponential curve, but not as exaggerated as an actual exponential curve.
//      In essence, this makes louder volumes brighter, and lower volumes dimmer, to be more visually distinct.
///////////////////////////////////////////////////////////////////////////////////////////////////////////////


//PULSE
//Pulse from center of the strand
void Pulse() {

  fade(0.75);   //Listed below, this function simply dims the colors a little bit each pass of loop()

  //Advances the palette to the next noticeable color if there is a "bump"
  if (bump) gradient += thresholds[palette] / 24;

  //If it's silent, we want the fade effect to take over, hence this if-statement
  if (volume > 0) {
    uint32_t col = ColorPalette(-1); //Our retrieved 32-bit color

    //These variables determine where to start and end the pulse since it starts from the middle of the strand.
    //  The quantities are stored in variables so they only have to be computed once (plus we use them in the loop).
    int start = LED_HALF - (LED_HALF * (volume / maxVol));
    int finish = LED_HALF + (LED_HALF * (volume / maxVol)) + strand.numPixels() % 2;
    //Listed above, LED_HALF is simply half the number of LEDs on your strand. ↑ this part adjusts for an odd quantity.

    for (int i = start; i < finish; i++) {

      //"damp" creates the fade effect of being dimmer the farther the pixel is from the center of the strand.
      //  It returns a value between 0 and 1 that peaks at 1 at the center of the strand and 0 at the ends.
      float damp = sin((i - start) * PI / float(finish - start));

      //Squaring damp creates more distinctive brightness.
      damp = pow(damp, 2.0);

      //Fetch the color at the current pixel so we can see if it's dim enough to overwrite.
      uint32_t col2 = strand.getPixelColor(i);

      //Takes advantage of one for loop to do the following:
      // Appropriatley adjust the brightness of this pixel using location, volume, and "knob"
      // Take the average RGB value of the intended color and the existing color, for comparison
      uint8_t colors[3];
      float avgCol = 0, avgCol2 = 0;
      for (int k = 0; k < 3; k++) {
        //colors[k] = split(col, k) * damp * knob * pow(volume / maxVol, 2);
        colors[k] = split(col, k) * damp * pow(volume / maxVol, 2);
        avgCol += colors[k];
        avgCol2 += split(col2, k);
      }
      avgCol /= 3.0, avgCol2 /= 3.0;

      //Compare the average colors as "brightness". Only overwrite dim colors so the fade effect is more apparent.
      if (avgCol > avgCol2) strand.setPixelColor(i, strand.Color(colors[0], colors[1], colors[2]));
    }
  }
  //This command actually shows the lights. If you make a new visualization, don't forget this!
  strand.show();
}


//PALETTEPULSE
//Same as Pulse(), but colored the entire pallet instead of one solid color
void PalettePulse() {
  fade(0.75);
  if (bump) gradient += thresholds[palette] / 24;
  if (volume > 0) {
    int start = LED_HALF - (LED_HALF * (volume / maxVol));
    int finish = LED_HALF + (LED_HALF * (volume / maxVol)) + strand.numPixels() % 2;
    for (int i = start; i < finish; i++) {
      float damp = sin((i - start) * PI / float(finish - start));
      damp = pow(damp, 2.0);

      //This is the only difference from Pulse(). The color for each pixel isn't the same, but rather the
      //  entire gradient fitted to the spread of the pulse, with some shifting from "gradient".
      int val = thresholds[palette] * (i - start) / (finish - start);
      val += gradient;
      uint32_t col = ColorPalette(val);

      uint32_t col2 = strand.getPixelColor(i);
      uint8_t colors[3];
      float avgCol = 0, avgCol2 = 0;
      for (int k = 0; k < 3; k++) {
        //colors[k] = split(col, k) * damp * knob * pow(volume / maxVol, 2);
        colors[k] = split(col, k) * damp *  pow(volume / maxVol, 2);
        avgCol += colors[k];
        avgCol2 += split(col2, k);
      }
      avgCol /= 3.0, avgCol2 /= 3.0;
      if (avgCol > avgCol2) strand.setPixelColor(i, strand.Color(colors[0], colors[1], colors[2]));
    }
  }
  strand.show();
}
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

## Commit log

2022-08-28 Update Jukebox_LEDS.ino
    fixed typo on Line 144.
    [Jukebox_LEDS.ino]
2022-08-28 Lights now track evenly up each side
    In animated lights mode, the lights now track evenly up each side.
